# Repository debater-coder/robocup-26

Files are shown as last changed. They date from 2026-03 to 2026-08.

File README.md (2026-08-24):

# Team High Scorers RoboCup 2026 Repository

This is the monorepo for the High Scorers RoboCup Junior Opens Soccer team. When browsing code,
it is highly recommended to browse in an editor with "Go to definition" support. If you are viewing from
GitHub, press the `.` key to open in an online VSCode instance.

## Project structure

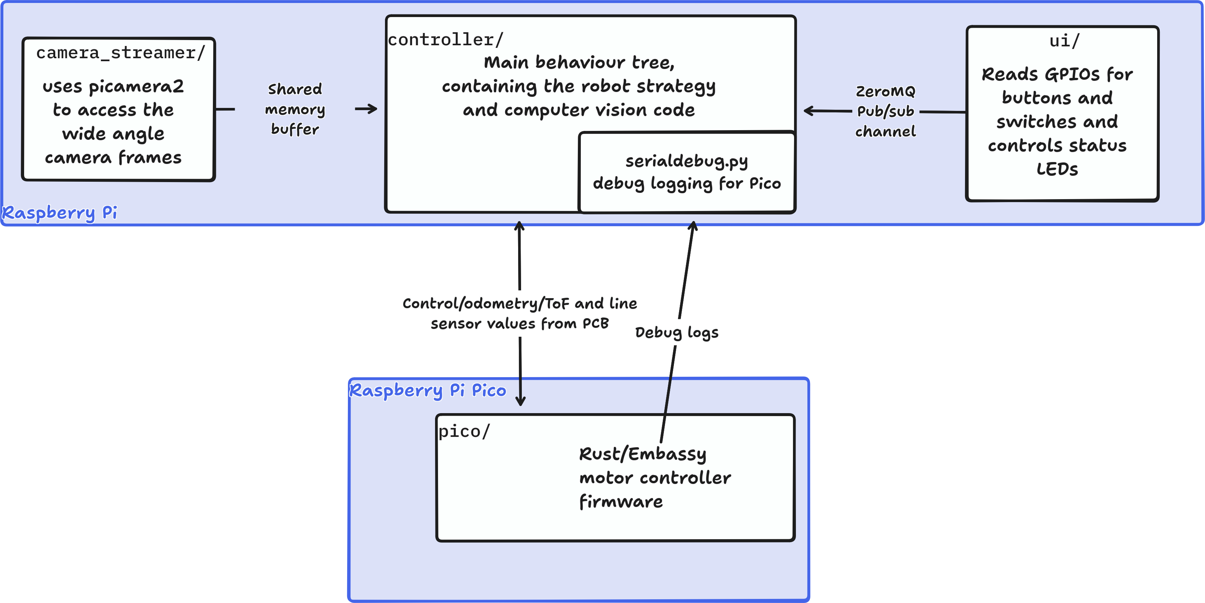
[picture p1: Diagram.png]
Archicture Diagram


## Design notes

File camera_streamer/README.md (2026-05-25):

Reads a frame from the camera, and sends it to the controller. Uses
shared memory to share the frames.

```bash
sudo apt install python3-numpy
```

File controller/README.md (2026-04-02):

# Robot Soccer Controller

This is the central control software for the robot, running on a Raspberry Pi.
It is responsible for:

- vision (detections of field, ball and other robots),
- sending actuator commands over serial
- performing closed loop control to determine actuator commands based on a target value
- computing target values based on a soccer strategy

## Infrastructure

Dependencies are managed by the `uv` python package manager. This package manager itself
is installed via a Nix flake.

To run the flake shell, run inside of this folder:

```bash
nix develop
```

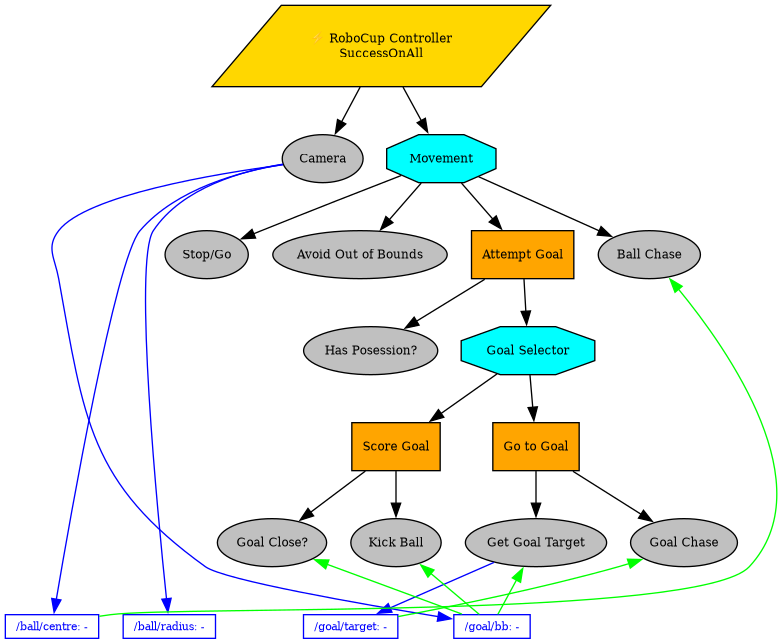
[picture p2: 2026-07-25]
controller/robocup_controller.png

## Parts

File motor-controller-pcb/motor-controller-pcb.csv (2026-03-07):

Id | Designator | Footprint | Quantity | Designation | Supplier and ref
1 | J7 | PinHeader_1x10_P2.54mm_Vertical | 1 | GND
2 | J6 | SolderWire-2sqmm_1x02_P7.8mm_D2mm_OD3.9mm_Relief2x | 1 | Battery Connector
3 | C2,C3,C4 | C_0805_2012Metric | 3 | 100.0nF
4 | J11 | PinHeader_1x05_P2.54mm_Vertical | 1 | Conn_01x05_Pin
5 | U3,U1,U2 | DRI044 | 3 | ~
6 | SW1 | SolderWire-2sqmm_1x02_P7.8mm_D2mm_OD3.9mm_Relief2x | 1 | Battery Switch
7 | TP1 | TestPoint_Pad_1.5x1.5mm | 1 | 5V TestPoint
8 | J12 | TerminalBlock_MaiXu_MX126-5.0-02P_1x02_P5.00mm | 1 | V_Batt
9 | A1 | RaspberryPi_Pico_Common_Unspecified | 1 | RaspberryPi_Pico
10 | J5 | JST_PH_B6B-PH-K_1x06_P2.00mm_Vertical | 1 | Dribbler Motor
11 | TP2 | TestPoint_Pad_1.5x1.5mm | 1 | GND TestPoint
12 | J10 | PinHeader_1x10_P2.54mm_Vertical | 1 | 3.0V3
13 | F1 | Fuseholder_Clip-5x20mm_Littelfuse_100_Inline_P20.50x4.60mm_D1.30mm_Horizontal | 1 | Fuse
14 | TP3 | TestPoint_Pad_1.5x1.5mm | 1 | V_Batt Test Point
15 | TP4 | TestPoint_Pad_1.5x1.5mm | 1 | 3V3 Test Point
16 | J9 | PinHeader_1x10_P2.54mm_Vertical | 1 | V_Batt
17 | C1 | CP_Radial_D8.0mm_P3.50mm | 1 | 470.0uF
18 | J8 | PinHeader_1x10_P2.54mm_Vertical | 1 | 5.0V
19 | J3 | JST_PH_B6B-PH-K_1x06_P2.00mm_Vertical | 1 | Motor 3
20 | J2 | JST_PH_B6B-PH-K_1x06_P2.00mm_Vertical | 1 | Motor 2
21 | J4 | JST_PH_B6B-PH-K_1x06_P2.00mm_Vertical | 1 | Motor 4
22 | J1 | JST_PH_B6B-PH-K_1x06_P2.00mm_Vertical | 1 | Motor 1

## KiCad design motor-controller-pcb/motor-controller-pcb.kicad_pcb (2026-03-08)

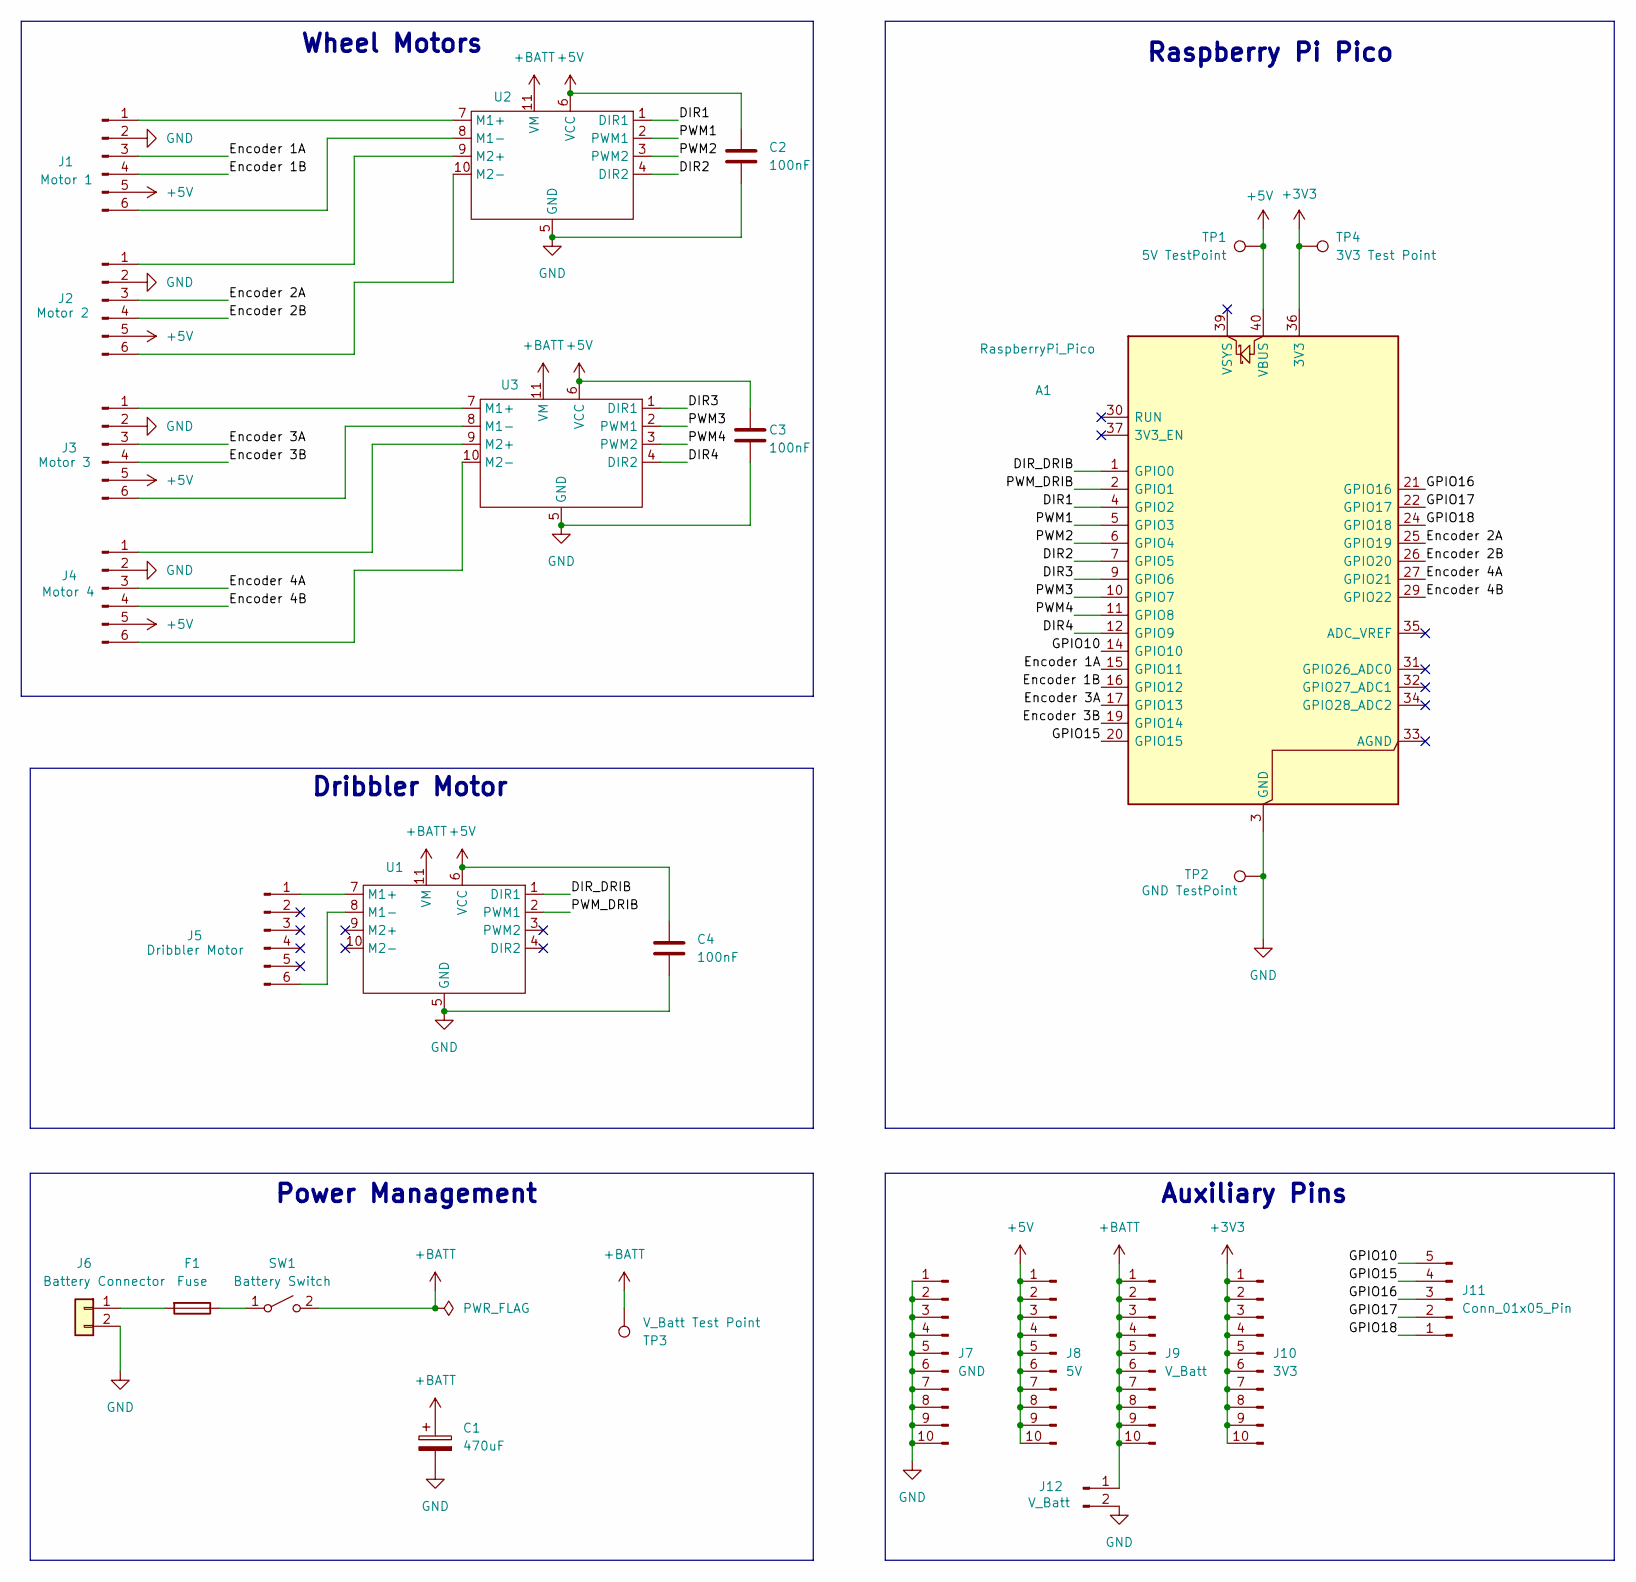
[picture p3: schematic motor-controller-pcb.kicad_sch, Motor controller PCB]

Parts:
A1: RaspberryPi_Pico; RaspberryPi_Pico_Common_Unspecified
C1: 470uF; CP_Radial_D8.0mm_P3.50mm
C2, C3, C4: 100nF; C_0805_2012Metric
F1: Fuse; Fuseholder_Clip-5x20mm_Littelfuse_100_Inline_P20.50x4.60mm_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
J1: Motor 1; JST_PH_B6B-PH-K_1x06_P2.00mm_Vertical
J2: Motor 2; JST_PH_B6B-PH-K_1x06_P2.00mm_Vertical
J3: Motor 3; JST_PH_B6B-PH-K_1x06_P2.00mm_Vertical
J4: Motor 4; JST_PH_B6B-PH-K_1x06_P2.00mm_Vertical
J5: Dribbler Motor; JST_PH_B6B-PH-K_1x06_P2.00mm_Vertical
J6: Battery Connector; SolderWire-4sqmm_1x02_P12mm_D3mm_OD6mm_Relief
J7: GND; PinHeader_1x10_P2.54mm_Vertical
J8: 5V; PinHeader_1x10_P2.54mm_Vertical
J9: V_Batt; PinHeader_1x10_P2.54mm_Vertical
J10: 3V3; PinHeader_1x10_P2.54mm_Vertical
J11: Conn_01x05_Pin; PinHeader_1x05_P2.54mm_Vertical
J12: V_Batt; TerminalBlock_MaiXu_MX126-5.0-02P_1x02_P5.00mm
SW1: Battery Switch; SolderWire-4sqmm_1x02_P12mm_D3mm_OD6mm_Relief
TP1: 5V TestPoint; TestPoint_Pad_1.5x1.5mm
TP2: GND TestPoint; TestPoint_Pad_1.5x1.5mm
TP3: V_Batt Test Point; TestPoint_Pad_1.5x1.5mm
TP4: 3V3 Test Point; TestPoint_Pad_1.5x1.5mm
U1, U2, U3: DRI0044

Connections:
+3V3: A1.36 (3V3), J10.1, J10.2, J10.3, J10.4, J10.5, J10.6, J10.7, J10.8, J10.9, J10.10, TP4.1
+5V: A1.40 (VBUS), C2.1, C3.1, C4.1, J1.5, J2.5, J3.5, J4.5, J8.1, J8.2, J8.3, J8.4, J8.5, J8.6, J8.7, J8.8, J8.9, J8.10, TP1.1, U1.6 (VCC), U2.6 (VCC), U3.6 (VCC)
+BATT: C1.1, J9.1, J9.2, J9.3, J9.4, J9.5, J9.6, J9.7, J9.8, J9.9, J9.10, J12.1, SW1.2 (B), TP3.1, U1.11 (VM), U2.11 (VM), U3.11 (VM)
/DIR1: A1.4 (GPIO2), U2.1 (DIR1)
/DIR2: A1.7 (GPIO5), U2.4 (DIR2)
/DIR3: A1.9 (GPIO6), U3.1 (DIR1)
/DIR4: A1.12 (GPIO9), U3.4 (DIR2)
/DIR_DRIB: A1.1 (GPIO0), U1.1 (DIR1)
/Encoder 1A: A1.15 (GPIO11), J1.3
/Encoder 1B: A1.16 (GPIO12), J1.4
/Encoder 2A: A1.25 (GPIO19), J2.3
/Encoder 2B: A1.26 (GPIO20), J2.4
/Encoder 3A: A1.17 (GPIO13), J3.3
/Encoder 3B: A1.19 (GPIO14), J3.4
/Encoder 4A: A1.27 (GPIO21), J4.3
/Encoder 4B: A1.29 (GPIO22), J4.4
/GPIO10: A1.14 (GPIO10), J11.5
/GPIO15: A1.20 (GPIO15), J11.4
/GPIO16: A1.21 (GPIO16), J11.3
/GPIO17: A1.22 (GPIO17), J11.2
/GPIO18: A1.24 (GPIO18), J11.1
/PWM1: A1.5 (GPIO3), U2.2 (PWM1)
/PWM2: A1.6 (GPIO4), U2.3 (PWM2)
/PWM3: A1.10 (GPIO7), U3.2 (PWM1)
/PWM4: A1.11 (GPIO8), U3.3 (PWM2)
/PWM_DRIB: A1.2 (GPIO1), U1.2 (PWM1)
GND: A1.3 (GND), A1.8 (GND), A1.13 (GND), A1.18 (GND), A1.23 (GND), A1.28 (GND), A1.38 (GND), C1.2, C2.2, C3.2, C4.2, J1.2, J2.2, J3.2, J4.2, J6.2, J7.1, J7.2, J7.3, J7.4, J7.5, J7.6, J7.7, J7.8, J7.9, J7.10, J12.2, TP2.1, U1.5 (GND), U2.5 (GND), U3.5 (GND)
unnamed: J1.1, U2.7 (M1+)
unnamed: J1.6, U2.8 (M1-)
unnamed: J2.1, U2.9 (M2+)
unnamed: J2.6, U2.10 (M2-)
unnamed: J3.1, U3.7 (M1+)
unnamed: J3.6, U3.8 (M1-)
unnamed: J4.1, U3.9 (M2+)
unnamed: J4.6, U3.10 (M2-)
unnamed: J5.1, U1.7 (M1+)
unnamed: J5.6, U1.8 (M1-)
unnamed: F1.2, J6.1
unnamed: F1.1, SW1.1 (A)

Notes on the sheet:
Raspberry Pi Pico
Dribbler Motor
Auxiliary Pins
Power Management
Wheel Motors

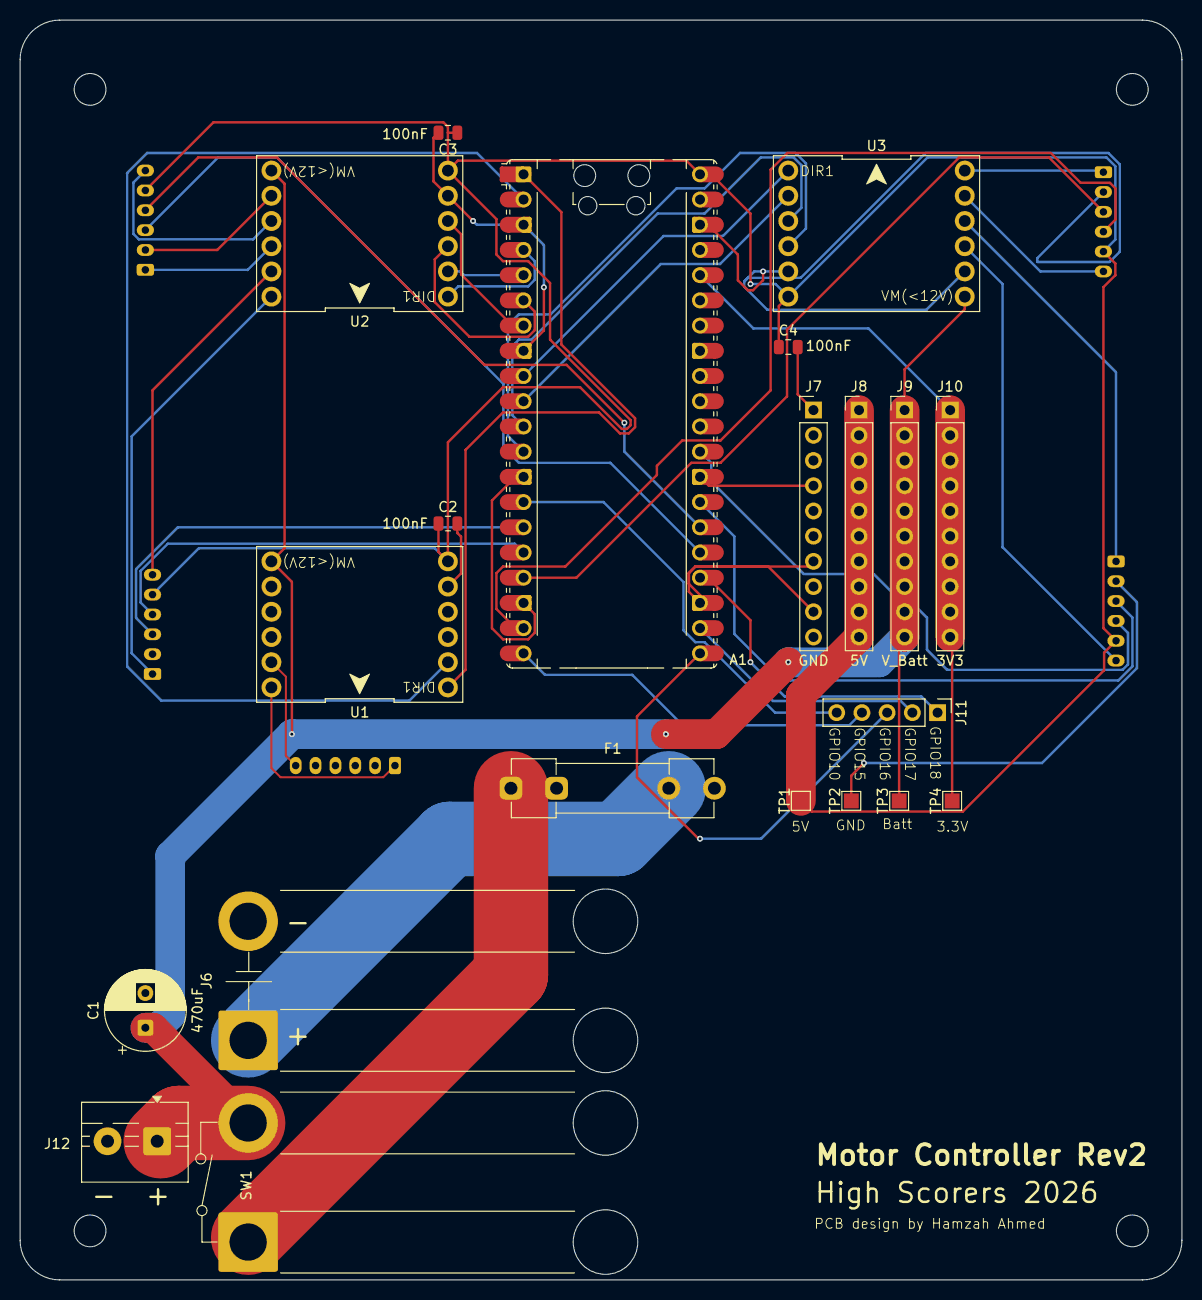
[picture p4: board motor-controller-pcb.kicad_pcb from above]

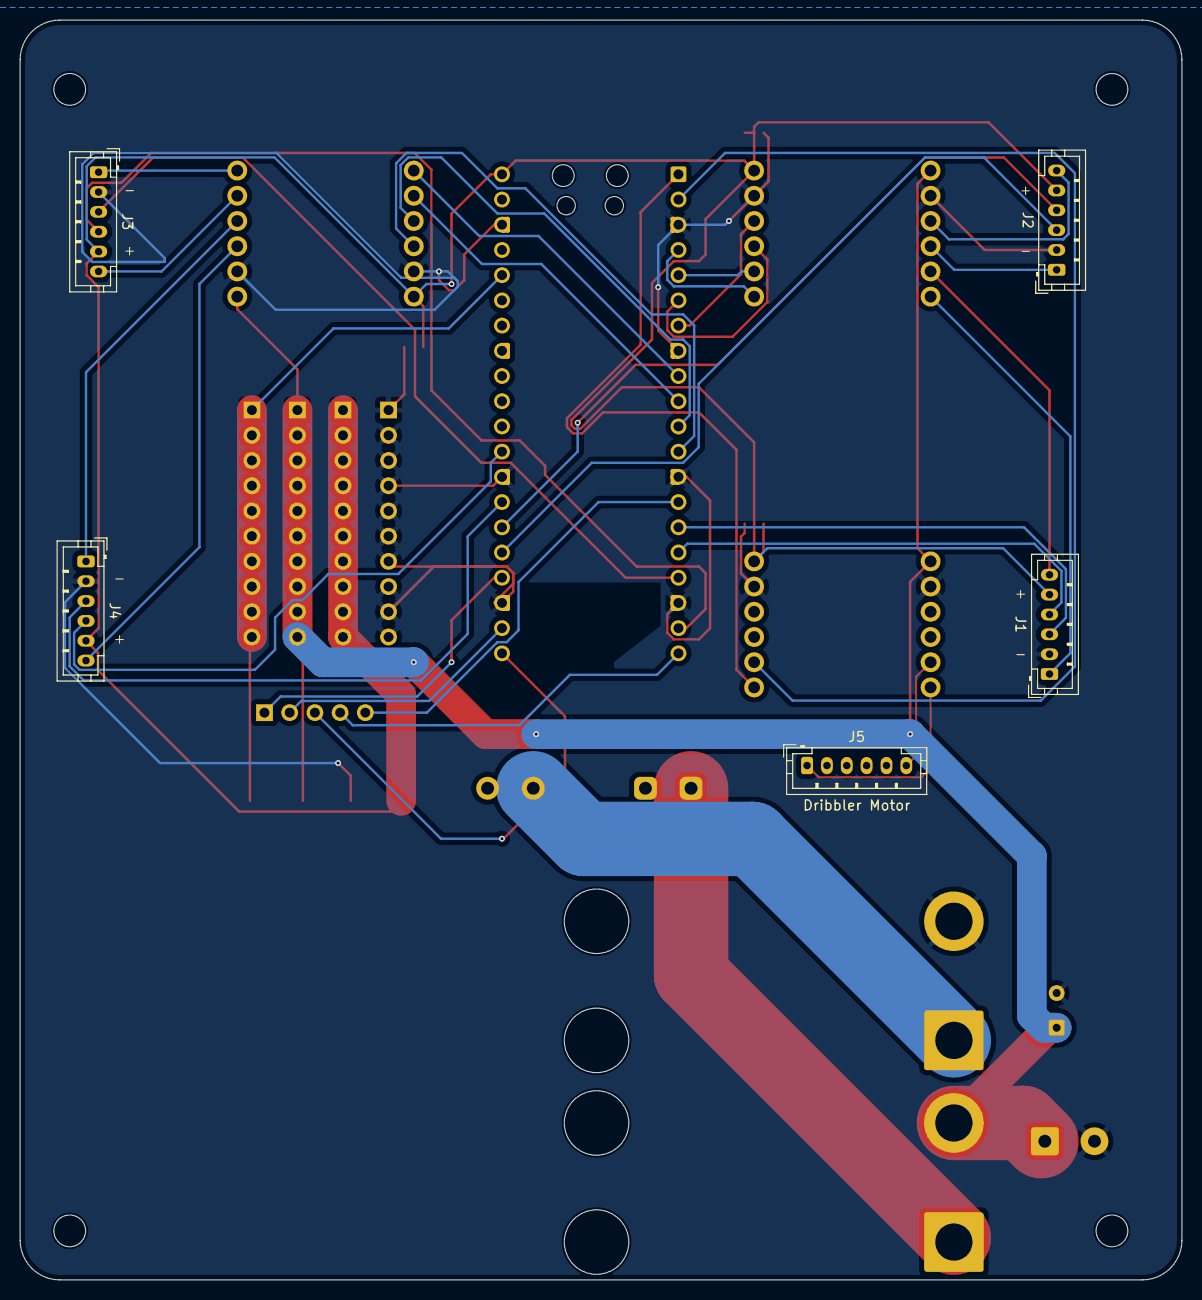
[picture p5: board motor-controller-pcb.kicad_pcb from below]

Board: 2 copper layers, 117.0 x 126.9 mm, 26 parts (5 on the bottom side), 39 nets.

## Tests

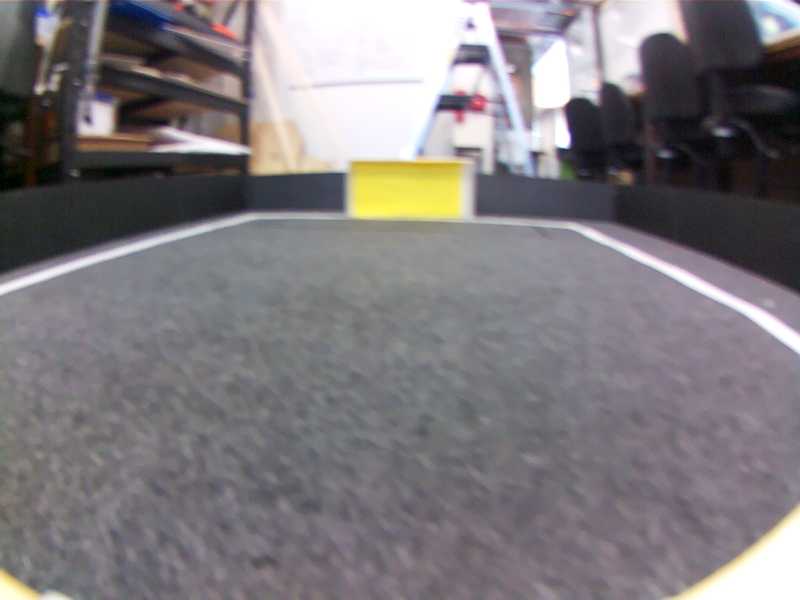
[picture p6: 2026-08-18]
controller/vision/test_images/facing_yellow.png

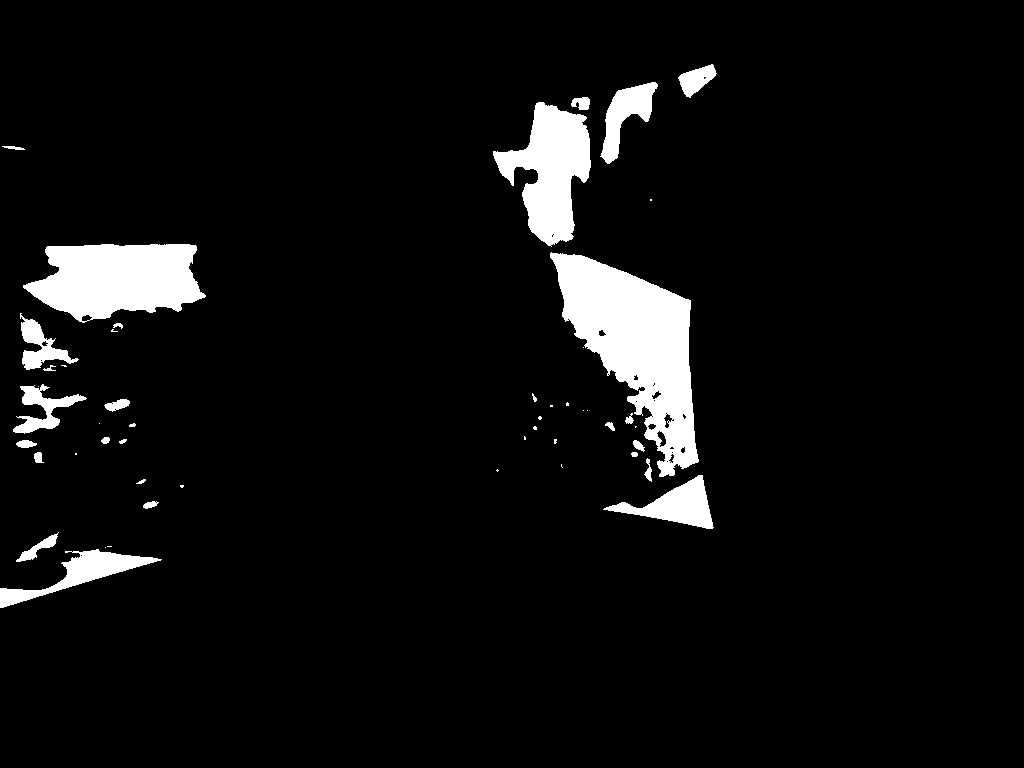
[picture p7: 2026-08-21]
controller/vision/test_images/very_white.png

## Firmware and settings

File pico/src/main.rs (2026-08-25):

#![no_std]
#![no_main]

use core::array;
use core::convert::Infallible;
use core::f32::consts::PI;
use core::iter::zip;

use crate::kinematics::{ChassisVector, WheelVector};
use crate::motor::{Motor, MotorFeedback};
use cobs::{CobsDecoder, CobsEncoder};
use embassy_executor::Spawner;
use embassy_futures::join::join;
use embassy_rp::gpio::{Input, Level, Output, Pull};
use embassy_rp::peripherals::{PIO0, USB};
use embassy_rp::pio::Pio;
use embassy_rp::pwm::{Config as PwmConfig, Pwm, SetDutyCycle};
use embassy_rp::usb::{Driver, Instance};
use embassy_rp::watchdog::Watchdog;
use embassy_rp::{bind_interrupts, i2c};
use embassy_sync::blocking_mutex::raw::CriticalSectionRawMutex;
use embassy_sync::signal::Signal;
use embassy_sync::watch::Watch;
use embassy_time::{with_timeout, Delay, Duration, Instant, Ticker, Timer};
use embassy_usb::class::cdc_acm::{CdcAcmClass, State};
use embassy_usb::driver::EndpointError;
use embassy_usb::{Builder, Config};
use embedded_hal::digital::{ErrorType, OutputPin};
use log::{error, info, warn};
use vl53l0x_simple::Vl53l0x;

const PWM_DIV_INT: u8 = 64;
const PWM_TOP: u16 = 46_874;

use {defmt_rtt as _, panic_probe as _};

use encoder::{Direction, PioEncoder, PioEncoderProgram};

mod encoder;
mod kinematics;
mod motor;

bind_interrupts!(struct Irqs {
    PIO0_IRQ_0 => embassy_rp::pio::InterruptHandler<PIO0>;
    USBCTRL_IRQ => embassy_rp::usb::InterruptHandler<USB>;
});

/// CHASSIS_VEL_CONTROL_SIGNAL is in robot local coordinate frame
static CHASSIS_VEL_CONTROL_SIGNAL: Signal<CriticalSectionRawMutex, ChassisVector> = Signal::new();
static CHASSIS_DISPLACEMENT_WATCH: Watch<CriticalSectionRawMutex, ChassisVector, 4> = Watch::new();

static DRIBBLER_CONTROL_SIGNAL: Signal<CriticalSectionRawMutex, i32> = Signal::new();
static TOF_DISTANCE_SIGNAL: Signal<CriticalSectionRawMutex, u16> = Signal::new();
static RESET_WATCH: Watch<CriticalSectionRawMutex, bool, 8> = Watch::new();

static ODOM_WATCH_FL: Watch<CriticalSectionRawMutex, i32, 8> = Watch::new();
static ODOM_WATCH_FR: Watch<CriticalSectionRawMutex, i32, 8> = Watch::new();
static ODOM_WATCH_RL: Watch<CriticalSectionRawMutex, i32, 8> = Watch::new();
static ODOM_WATCH_RR: Watch<CriticalSectionRawMutex, i32, 8> = Watch::new();

const PULSES_PER_MM: f32 = 1050. / (48.0 * PI);

#[embassy_executor::task]
async fn led_task(mut led: Output<'static>) {
    let period: Duration = Duration::from_secs(2);

    loop {
        info!("led on!");
        led.set_high();
        Timer::after(period / 2).await;

        info!("led off!");
        led.set_low();
        Timer::after(period / 2).await;
    }
}

macro_rules! odom_task {
    ($name:ident, $pin:ty) => {
        #[embassy_executor::task]
        async fn $name(
            mut encoder: $pin,
            watch: &'static Watch<CriticalSectionRawMutex, i32, 8>,
            reverse: bool,
        ) {
            let mut count: i32 = 0;
            let sender = watch.sender();
            loop {
                count += match encoder.read().await {
                    Direction::Clockwise => 1,
                    Direction::CounterClockwise => -1,
                } * (if reverse { -1 } else { 1 });
                sender.send(count);
            }
        }
    };
}

#[embassy_executor::task]
async fn dribbler_task(mut dribbler: Motor) {
    loop {
        let next_speed = with_timeout(Duration::from_millis(500), DRIBBLER_CONTROL_SIGNAL.wait())
            .await
            .unwrap_or(0);
        dribbler.set_speed(next_speed);
    }
}

#[embassy_executor::task]
async fn kinematics_task(
    fl: MotorFeedback,
    rl: MotorFeedback,
    rr: MotorFeedback,
    fr: MotorFeedback,
) {
    let mut ticker = Ticker::every(Duration::from_hz(20));
    let mut motors = [fl, rl, rr, fr];
    let mut recv = [
        ODOM_WATCH_FL.receiver().unwrap(),
        ODOM_WATCH_RL.receiver().unwrap(),
        ODOM_WATCH_RR.receiver().unwrap(),
        ODOM_WATCH_FR.receiver().unwrap(),
    ];

    let displ_sender = CHASSIS_DISPLACEMENT_WATCH.sender();
    let mut displ_recv = CHASSIS_DISPLACEMENT_WATCH.receiver().unwrap();

    let mut last_command = Instant::now();

    loop {
        if let Some(chassis_vel) = CHASSIS_VEL_CONTROL_SIGNAL.try_take() {
            // Compute wheel velocities from chassis velocities
            let wheel_vels = chassis_vel.inverse_kinematics();
            for (i, motor) in motors.iter_mut().enumerate() {
                motor.target = wheel_vels.as_array()[i] as i32;
            }

            last_command = Instant::now();
        } else {
            if last_command.elapsed() > Duration::from_millis(500) {
                for (i, motor) in motors.iter_mut().enumerate() {
                    motor.target = 0;
                }
            }
        }

        for (motor, signal) in zip(motors.iter_mut(), recv.iter_mut()) {
            motor.update(signal.try_get().unwrap_or(0));
        }

        // Get displacement
        let wheel_displ = WheelVector {
            fl: motors[0].last_diff as f32 / PULSES_PER_MM,
            rl: motors[1].last_diff as f32 / PULSES_PER_MM,
            rr: motors[2].last_diff as f32 / PULSES_PER_MM,
            fr: motors[3].last_diff as f32 / PULSES_PER_MM,
        };

        let chassis_displ = wheel_displ.forwards_kinematics();
        let curr_displ = displ_recv.try_get().unwrap_or_default();

        displ_sender.send(curr_displ * chassis_displ);

        ticker.next().await;
    }
}

struct NoopOutput;
impl OutputPin for NoopOutput {
    fn set_low(&mut self) -> Result<(), Self::Error> {
        Ok(())
    }

    fn set_high(&mut self) -> Result<(), Self::Error> {
        Ok(())
    }
}

impl ErrorType for NoopOutput {
    type Error = Infallible;
}

/// This will allow resets in case of panic (but not any other type of hand)
#[embassy_executor::task]
async fn feed_watchdog(mut watchdog: Watchdog) {
    let mut recv = RESET_WATCH.receiver().unwrap();
    loop {
        if !recv.try_get().unwrap_or(false) {
            watchdog.feed();
            Timer::after_millis(100).await;
        }
    }
}

#[embassy_executor::main]
async fn main(spawner: Spawner) {
    let p = embassy_rp::init(Default::default());

    let mut watchdog = Watchdog::new(p.WATCHDOG);
    watchdog.start(Duration::from_millis(500));
    spawner.spawn(feed_watchdog(watchdog)).unwrap();

    let led = Output::new(p.PIN_25, Level::Low);
    spawner.spawn(led_task(led)).unwrap();

    let dribbler = Motor::new(
        Output::new(p.PIN_0, Level::Low),
        Pwm::new_output_b(p.PWM_SLICE0, p.PIN_1, Default::default())
            .split()
            .1
            .unwrap(),
        true,
    );
    spawner.spawn(dribbler_task(dribbler)).unwrap();

    let Pio {
        mut common,
        sm0,
        sm1,
        sm2,
        sm3,
        ..
    } = Pio::new(p.PIO0, Irqs);

    let prg = PioEncoderProgram::new(&mut common);
    let encoder0 = PioEncoder::new(&mut common, sm0, p.PIN_11, p.PIN_12, &prg, 500_000);
    let encoder1 = PioEncoder::new(&mut common, sm1, p.PIN_19, p.PIN_20, &prg, 500_000);
    let encoder2 = PioEncoder::new(&mut common, sm2, p.PIN_13, p.PIN_14, &prg, 500_000);
    let encoder3 = PioEncoder::new(&mut common, sm3, p.PIN_21, p.PIN_22, &prg, 500_000);

    odom_task!(odom_task_0, PioEncoder<'static, PIO0, 0>);
    odom_task!(odom_task_1, PioEncoder<'static, PIO0, 1>);
    odom_task!(odom_task_2, PioEncoder<'static, PIO0, 2>);
    odom_task!(odom_task_3, PioEncoder<'static, PIO0, 3>);

    spawner
        .spawn(odom_task_0(encoder0, &ODOM_WATCH_FL, true))
        .unwrap();
    spawner
        .spawn(odom_task_1(encoder1, &ODOM_WATCH_RL, true))
        .unwrap();
    spawner
        .spawn(odom_task_2(encoder2, &ODOM_WATCH_RR, false))
        .unwrap();
    spawner
        .spawn(odom_task_3(encoder3, &ODOM_WATCH_FR, false))
        .unwrap();

    spawner
        .spawn(kinematics_task(
            MotorFeedback::new(
                Output::new(p.PIN_2, Level::Low),
                Pwm::new_output_b(p.PWM_SLICE1, p.PIN_3, Default::default())
                    .split()
                    .1
                    .unwrap(),
                0,
                true,
            ),
            MotorFeedback::new(
                Output::new(p.PIN_5, Level::Low),
                Pwm::new_output_a(p.PWM_SLICE2, p.PIN_4, Default::default())
                    .split()
                    .0
                    .unwrap(),
                1,
                false,
            ),
            MotorFeedback::new(
                Output::new(p.PIN_6, Level::Low),
                Pwm::new_output_b(p.PWM_SLICE3, p.PIN_7, Default::default())
                    .split()
                    .1
                    .unwrap(),
                2,
                false,
            ),
            MotorFeedback::new(
                Output::new(p.PIN_9, Level::Low),
                Pwm::new_output_a(p.PWM_SLICE4, p.PIN_8, Default::default())
                    .split()
                    .0
                    .unwrap(),
                3,
                true,
            ),
        ))
        .unwrap();

    // Create the driver, from the HAL.
    let driver = Driver::new(p.USB, Irqs);

    // Create embassy-usb Config
    let mut config = Config::new(0xc0de, 0xcafe);
    config.manufacturer = Some("High Scorers");
    config.product = Some("USB Motor Controller");
    config.max_power = 100;
    config.max_packet_size_0 = 64;

    // Create embassy-usb DeviceBuilder using the driver and config.
    // It needs some buffers for building the descriptors.
    let mut config_descriptor = [0; 256];
    let mut bos_descriptor = [0; 256];
    let mut control_buf = [0; 64];

    let mut state = State::new();
    let mut logger_state = State::new();

    let mut builder = Builder::new(
        driver,
        config,
        &mut config_descriptor,
        &mut bos_descriptor,
        &mut [], // no msos descriptors
        &mut control_buf,
    );

    // Create classes on the builder.
    let mut class = CdcAcmClass::new(&mut builder, &mut state, 64);

    // Create a class for the logger
    let logger_class = CdcAcmClass::new(&mut builder, &mut logger_state, 64);

    // Creates the logger and returns the logger future
    // Note: You'll need to use log::info! afterwards instead of info! for this to work (this also applies to all the other log::* macros)
    let log_fut = embassy_usb_logger::with_class!(1024, log::LevelFilter::Info, logger_class);

    // Build the builder.
    let mut usb = builder.build();

    // Run the USB device.
    let usb_fut = usb.run();

    let sda = p.PIN_16;
    let scl = p.PIN_17;
    let i2c = i2c::I2c::new_blocking(p.I2C0, scl, sda, i2c::Config::default());

    let mut tof = Vl53l0x::new(i2c, NoopOutput, vl53l0x_simple::DEFAULT_ADDRESS, &mut Delay);

    let tof_fut = async {
        if let Ok(tof) = &mut tof {
            loop {
                if let Ok(Some(reading)) = tof.try_read() {
                    TOF_DISTANCE_SIGNAL.signal(reading);
                } else {
                    warn!("Failed to read from vl53l0x!")
                }
                Timer::after_millis(100).await;
            }
        }
    };

    let mut servo_config: PwmConfig = Default::default();
    servo_config.top = PWM_TOP;
    servo_config.divider = PWM_DIV_INT.into();

    let mut servo = Pwm::new_output_b(p.PWM_SLICE7, p.PIN_15, servo_config);

    let fut = async {
        loop {
            match servo.set_duty_cycle_fraction(25, 1000) {
                Ok(_) => {}
                Err(_) => warn!("Error"),
            };
            Timer::after(Duration::from_millis(500)).await;
            match servo.set_duty_cycle_fraction(75, 1000) {
                Ok(_) => {}
                Err(_) => warn!("Error"),
            };
            Timer::after(Duration::from_millis(500)).await;
        }
    };

    let command_fut = async {
        loop {
            class.wait_connection().await;
            log::info!("Connected");
            let _ = handle_commands(&mut class).await;
            log::info!("Disconnected");
        }
    };

    join(
        fut,
        join(tof_fut, join(usb_fut, join(command_fut, log_fut))),
    )
    .await;
}

struct Disconnected {}

impl From<EndpointError> for Disconnected {
    fn from(val: EndpointError) -> Self {
        match val {
            EndpointError::BufferOverflow => panic!("Buffer overflow"),
            EndpointError::Disabled => Disconnected {},
        }
    }
}

async fn handle_commands<'d, T: Instance + 'd>(
    class: &mut CdcAcmClass<'d, Driver<'d, T>>,
) -> Result<(), Disconnected> {
    let mut buf = [0; 64];
    let mut dest = [0; 1024];
    let mut decoder = CobsDecoder::new(&mut dest);
    let mut recv = CHASSIS_DISPLACEMENT_WATCH.receiver().unwrap();
    let reset_sender = RESET_WATCH.sender();

    loop {
        let n = class.read_packet(&mut buf).await?;
        let data = &buf[..n];

        'outer: for byte in data {
            match decoder.feed(*byte) {
                Err(e) => {
                    warn!("Error parsing packet: {:?}", e);
                }
                Ok(None) => {}
                Ok(Some(n)) => {
                    // Hard reset
                    if n == 1 {
                        reset_sender.send(true);
                    } else if n != 16 {
                        warn!("Invalid packet size");
                    } else {
                        let mut control_dst = [0u8; 16];
                        control_dst.copy_from_slice(&decoder.dest()[..16]);
                        let x = i32::from_be_bytes(control_dst[..4].try_into().unwrap());
                        let y = i32::from_be_bytes(control_dst[4..8].try_into().unwrap());
                        let w = i32::from_be_bytes(control_dst[8..12].try_into().unwrap()); // deg/s
                        let dribbler_control =
                            i32::from_be_bytes(control_dst[12..16].try_into().unwrap());

                        info!("Received controls: {} {} {} {}", x, y, w, dribbler_control);

                        CHASSIS_VEL_CONTROL_SIGNAL.signal(ChassisVector {
                            x: (x as f32 * PULSES_PER_MM),
                            y: (y as f32 * PULSES_PER_MM),
                            w: (w as f32 * PI / 180.), // into rad/s
                        });

                        DRIBBLER_CONTROL_SIGNAL.signal(dribbler_control);

                        // Return odom of all wheels
                        let mut out_buf = [0u8; 62];
                        let mut encoder = CobsEncoder::new(&mut out_buf);

                        let odoms = recv.try_get().unwrap().as_int_array();
                        let tof_reading = TOF_DISTANCE_SIGNAL.try_take().unwrap_or(0);

                        let Ok(_) = encoder
                            .push(&array::from_fn::<_, 12, _>(|i| {
                                odoms[i / 4].to_be_bytes()[i % 4]
                            }))
                            .and_then(|_| encoder.push(&tof_reading.to_be_bytes()))
                            .and_then(|_| encoder.push(&[0]))
                        else {
                            warn!("Error encoding data!");
                            continue 'outer;
                        };

                        encoder.finalize();
                        class.write_packet(&[0]).await?;
                        class.write_packet(&out_buf).await?;
                        class.write_packet(&[0]).await?;
                    }
                }
            }
        }

        info!("data: {:?}", data);
    }
}

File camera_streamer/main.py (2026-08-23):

"""
Refer to:
https://stackoverflow.com/questions/66353952/how-to-pass-video-stream-from-one-python-script-to-another
for shared memory explanation
"""

from multiprocessing.shared_memory import SharedMemory
from time import sleep

import numpy as np
from picamera2 import Picamera2

cam = Picamera2()
config = cam.create_video_configuration(main={"size": (800, 600)})
cam.set_controls({"ExposureValue": -2.0})
cam.configure(config)
cam.start()
frame = np.rot90(cam.capture_array(), k=2, axes=(0, 1))


# Shared memory for the frame dimensions
frame_shape_shm = SharedMemory(name="frame_shape", create=True, size=frame.ndim * 4)
frame_shape = np.ndarray(3, buffer=frame_shape_shm.buf, dtype="i4")
frame_shape[:] = frame.shape

# Shared memory for the frame itself
frame_buffer_shm = SharedMemory(name="frame_buffer", create=True, size=frame.nbytes)
frame_buffer = np.ndarray(frame_shape, buffer=frame_buffer_shm.buf, dtype=frame.dtype)


try:
    while True:
        frame_buffer[:] = np.rot90(
            cam.capture_array(), k=2, axes=(0, 1)
        )  # in place updating of the buffer
        sleep(0.01)
finally:
    frame_buffer_shm.close()
    frame_shape_shm.close()

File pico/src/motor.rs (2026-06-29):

use embassy_rp::{
    gpio::{Level, Output},
    pwm::{PwmOutput, SetDutyCycle},
};
use embassy_time::{Duration, Instant};
use log::{info, warn};
use pid::Pid;

pub struct Motor {
    dir: Output<'static>,
    pwm: PwmOutput<'static>,
    /// Speed value from -100 to 100
    speed: i32,
    reversed: bool,
}

impl Motor {
    pub fn new(dir: Output<'static>, pwm: PwmOutput<'static>, reversed: bool) -> Self {
        Motor {
            dir,
            pwm,
            speed: 0,
            reversed,
        }
    }

    pub fn set_speed(&mut self, speed: i32) {
        self.speed = speed.clamp(-100, 100);
        self.dir.set_level(if (speed > 0) != self.reversed {
            Level::High
        } else {
            Level::Low
        });

        let abs_speed = self.speed.abs();
        self.pwm
            .set_duty_cycle_percent(if abs_speed > 10 { abs_speed } else { 0 } as u8)
            .unwrap();
    }

    pub fn get_speed(&self) -> i32 {
        self.speed
    }
}

pub struct MotorFeedback {
    motor: Motor,
    motor_id: u32,
    pid: Pid<f32>,
    /// target speed in pulses/s
    pub target: i32,
    last_instant: Instant,
    last_odom: i32,
    k_forward: f32,
    /// in pulses
    pub last_diff: i32,
}

impl MotorFeedback {
    pub fn new(dir: Output<'static>, pwm: PwmOutput<'static>, id: u32, reversed: bool) -> Self {
        let mut pid = Pid::new(0.0, 100.0);

        pid.p(0.03, 100.0);
        pid.i(0.003, 10.0);
        pid.d(0.003, 10.0);

        MotorFeedback {
            motor: Motor::new(dir, pwm, reversed),
            pid,
            target: 0,
            last_instant: Instant::now(),
            last_odom: 0,
            motor_id: id,
            k_forward: 0.030769231,
            last_diff: 0,
        }
    }

    /// Call at 20Hz
    pub fn update(&mut self, odom: i32) {
        self.last_diff = odom - self.last_odom; // This is a signed integer for direction
        let elapsed = self.last_instant.elapsed();
        self.last_instant = Instant::now();
        self.last_odom = odom;
        self.pid.setpoint(self.target as f32);

        if elapsed > Duration::from_millis(75) {
            warn!(
                "Too long between motor feedback, motor id: {}",
                self.motor_id
            );
            return;
        }

        if elapsed < Duration::from_millis(25) {
            warn!(
                "Too short between motor feedback, motor id: {}",
                self.motor_id
            );
            return;
        }

        // Hard cuttoff at target 0
        if self.target == 0 {
            self.motor.set_speed(0);
            return;
        }

        // Pulses / s
        let speed = (self.last_diff * 1000) / elapsed.as_millis() as i32;
        info!(
            "[SETPOINT_SPEED_{id}]: {setpoint} | [MEASURED_SPEED_{id}]: {measured}",
            id = self.motor_id,
            setpoint = self.target,
            measured = speed,
        );

        let feed_forward = self.target as f32 * self.k_forward;
        let pid_out = self.pid.next_control_output(speed as f32).output;
        let control_out = feed_forward as i32 + pid_out as i32;

        info!("[CONTROL_OUT_{}]: {}", self.motor_id, control_out);
        info!("[PID_OUT_{}]: {}", self.motor_id, pid_out);

        self.motor.set_speed(control_out);
    }
}

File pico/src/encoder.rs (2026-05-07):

//! Modified from `embassy_rp`
//! PIO backed quadrature encoder

use embassy_rp::gpio::Pull;
use embassy_rp::pio::{
    Common, Config, Direction as PioDirection, FifoJoin, Instance, LoadedProgram, PioPin,
    ShiftDirection, StateMachine,
};
use embassy_rp::pio_programs::clock_divider::calculate_pio_clock_divider;
use embassy_rp::Peri;

/// This struct represents an Encoder program loaded into pio instruction memory.
pub struct PioEncoderProgram<'a, PIO: Instance> {
    prg: LoadedProgram<'a, PIO>,
}

impl<'a, PIO: Instance> PioEncoderProgram<'a, PIO> {
    /// Load the program into the given pio
    pub fn new(common: &mut Common<'a, PIO>) -> Self {
        let prg = pio::pio_asm!("wait 1 pin 1", "wait 0 pin 1", "in pins, 2", "push",);

        let prg = common.load_program(&prg.program);

        Self { prg }
    }
}

/// Pio Backed quadrature encoder reader
pub struct PioEncoder<'d, T: Instance, const SM: usize> {
    sm: StateMachine<'d, T, SM>,
}

impl<'d, T: Instance, const SM: usize> PioEncoder<'d, T, SM> {
    /// Configure a state machine with the loaded [PioEncoderProgram]
    pub fn new(
        pio: &mut Common<'d, T>,
        mut sm: StateMachine<'d, T, SM>,
        pin_a: Peri<'d, impl PioPin>,
        pin_b: Peri<'d, impl PioPin>,
        program: &PioEncoderProgram<'d, T>,
        target_hz: u32,
    ) -> Self {
        let mut pin_a = pio.make_pio_pin(pin_a);
        let mut pin_b = pio.make_pio_pin(pin_b);
        pin_a.set_pull(Pull::Up);
        pin_b.set_pull(Pull::Up);
        sm.set_pin_dirs(PioDirection::In, &[&pin_a, &pin_b]);

        let mut cfg = Config::default();
        cfg.set_in_pins(&[&pin_a, &pin_b]);
        cfg.fifo_join = FifoJoin::RxOnly;
        cfg.shift_in.direction = ShiftDirection::Left;

        cfg.clock_divider = calculate_pio_clock_divider(target_hz);

        cfg.use_program(&program.prg, &[]);
        sm.set_config(&cfg);
        sm.set_enable(true);
        Self { sm }
    }

    /// Read a single count from the encoder
    pub async fn read(&mut self) -> Direction {
        loop {
            match self.sm.rx().wait_pull().await {
                0 => return Direction::CounterClockwise,
                1 => return Direction::Clockwise,
                _ => {}
            }
        }
    }
}

/// Encoder Count Direction
pub enum Direction {
    /// Encoder turned clockwise
    Clockwise,
    /// Encoder turned counter clockwise
    CounterClockwise,
}

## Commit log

2025-10-28 fix: only import cv2 typing when typechecking
    [main.py]
2025-10-28 fix: change blur size
    [main.py]
2025-10-28 fix: detect vaguely orange
    [main.py]
2025-11-03 fix: flip camera
2025-11-07 feat: echo test for pico
2025-11-07 feat: add rshell to pico
2025-11-07 Revert "feat: add rshell to pico"
    This reverts commit bd0b26686dfb8c57506edc8fa4abe32e96ba4601.
2025-11-08 feat: switch to rust for pico
2025-11-09 feat: use watchdog to automatically recover after failures
    [main.rs]
2025-11-21 feat: led for normal pico
2026-02-03 pico motor
2026-02-05 feat: pid motor control
2026-02-19 pcb work
    [motor-controller-pcb-B_Cu.gbr, motor-controller-pcb-B_Mask.gbr, motor-controller-pcb-B_Paste.gbr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]
2026-03-03 fix: change pcb footprint to jst ph
    [motor-controller-pcb.kicad_pcb, motor-controller-pcb.kicad_sch]
2026-03-05 feat: schematic improvement
    [motor-controller-pcb.kicad_sch]
2026-03-05 feat: capacitors and aux pins
    [motor-controller-pcb.kicad_sch]
2026-03-05 feat: pcb layout
    [motor-controller-pcb.kicad_pcb, motor-controller-pcb.kicad_sch]
2026-03-06 feat: final
    [motor-controller-pcb-B_Cu.gbr, motor-controller-pcb-B_Mask.gbr, motor-controller-pcb-B_Paste.gbr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]
2026-03-07 feat: pcb prettification
    [motor-controller-pcb.csv, motor-controller-pcb.kicad_pcb, motor-controller-pcb.kicad_sch]
2026-03-08 fix: make wire strain relief holes large enough
    [motor-controller-pcb.kicad_pcb, motor-controller-pcb.kicad_sch]
2026-03-15 feat: encoder and blinky tests
2026-03-16 feat: integrate quadrature encoder into main
2026-04-06 fix: log robot directions
    [main.rs]
2026-04-29 fix: reverse motor direction
    [main.rs]
2026-04-30 feat: fix all motor directions
    [main.rs]
2026-05-04 feat: pid control of individual motors
2026-05-07 feat: kinematics
2026-05-07 fix: encoder at higher clock rate
    [encoder.rs, main.rs]
2026-05-12 fix: actually clamp speed sent to motor
    [motor.rs]
2026-05-14 fix: logging and remove double pulse conversion
    [motor.rs, serialdebug.py]
2026-05-14 feat: tune pid
2026-05-15 feat: return displacement of chassis
2026-05-17 feat: controller-pico interop
2026-05-25 feat: camera streamer
2026-06-01 fix: rotate camera and slow framerate
    [camtest.py, main.py]
2026-06-01 fix: connect to central sever
    [camtest.py]
2026-06-01 fix: rgb image to jpg
    [camtest.py]
2026-06-04 feat: camera behaviour
2026-07-02 feat: switch to vl53l0x sensor
2026-07-03 feat: force forward when ball sensor detected
2026-07-03 fix: add default packet result
    [PicoCommand.py]
2026-07-03 fix: dribbler correct direction
    [PicoCommand.py]
2026-07-09 fix: print info in markdown
    [__main__.py]
2026-07-09 fix: use remote gpio over localhost
    [__main__.py]
2026-07-09 fix: switch to using lgpio
    [__main__.py]
2026-07-09 feat: get line data ir sensor
2026-07-10 fix: get ir info on every command
    [main.rs]
2026-07-10 feat: avoid out of bounds
    [root.py]
2026-07-10 feat: calibration script
2026-07-11 fix: not markdown now
    [__main__.py]
2026-07-25 feat: kick the ball when close to the goal
    This uses the visual size of the goal, and when close runs the dribbler
    in reverse to have a kicking effect.
    [root.py]
2026-07-26 fix: don't hardcode camera res
2026-07-27 fix: put correct behaviour
    [root.py]
2026-08-17 fix: fisheye calibration
2026-08-18 fix: use correct constants
    [calibrate.py]
2026-08-18 feat: good camera calibration parameters
2026-08-19 fix: run debug warping in another thread
2026-08-19 feat: hard reset command
    [main.rs, serialtest.py]
2026-08-19 fix: hard reset watch
    [main.rs]
2026-08-19 fix: connect to lowest port
    [serialtest.py]
2026-08-19 fix: use lowest port for serial communication in PicoCommand
    [PicoCommand.py]
2026-08-19 feat: autoreset pico when dodgy happen
2026-08-19 Revert "e"
    This reverts commit 3666992d3e127e42a78e36046e42d720c02a350a.
    [PicoCommand.py]
2026-08-19 Revert "feat: autoreset pico when dodgy happen"
    This reverts commit 5a75c9b52123aaa7117d552158a6f7b5746f635c.
    [PicoCommand.py]
2026-08-20 feat: LEDs
2026-08-23 fix: make camera darker
    [main.py]
2026-08-24 feat: do pid
2026-08-24 fix: filter out candidates too small
2026-08-25 fix: reconnect to serial
    [PicoCommand.py, main.rs]
2026-11-06 add CAD files
